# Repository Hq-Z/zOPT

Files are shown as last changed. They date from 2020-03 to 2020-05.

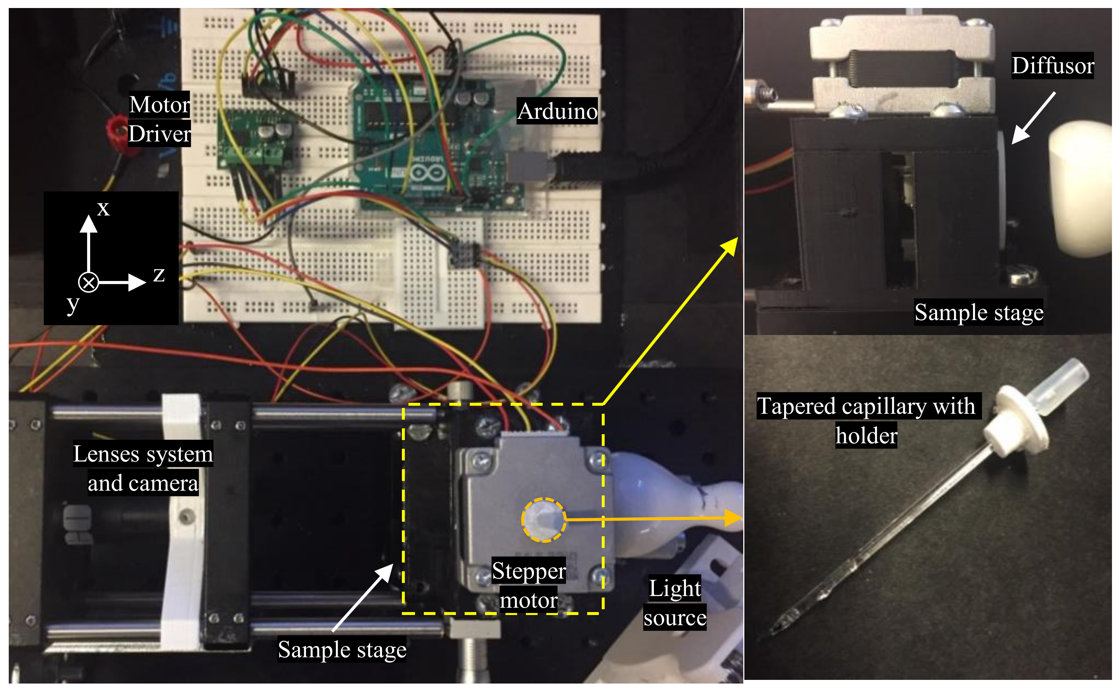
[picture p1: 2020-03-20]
1. 3D Models/SetupDemo/FigureS1.png

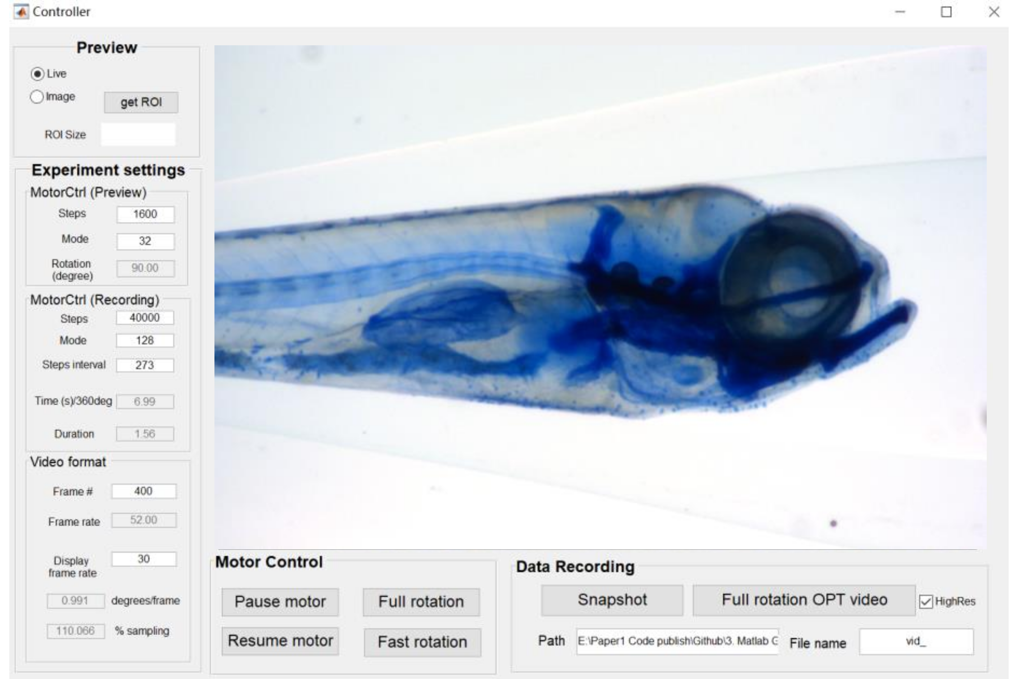
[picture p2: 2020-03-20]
3. Matlab GUI/GUI Demo/FigureS2.png

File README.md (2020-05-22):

# zOPT
This project contains an open-source implementation of an OPT platform. The 3D-printable components are provided to built your customized sample stage. We offer our open source MATLAB software with an GUI for OPT imaging. We developed a generalized automated workflow including a two-step registration approach for correcting the center of rotation and provide accurate and high-quality 3D reconstruction.

Here we provide the source codes and a user guide to built up the zOPT system. For sample data from the system, please follow this link,
https://sourceforge.net/projects/zopt-tomography-reconstruction.
We saved a bright field OPT tomography data recorded by our zOPT setup and it can be used to verify the algorithms for zOPT tomography reconstruction.

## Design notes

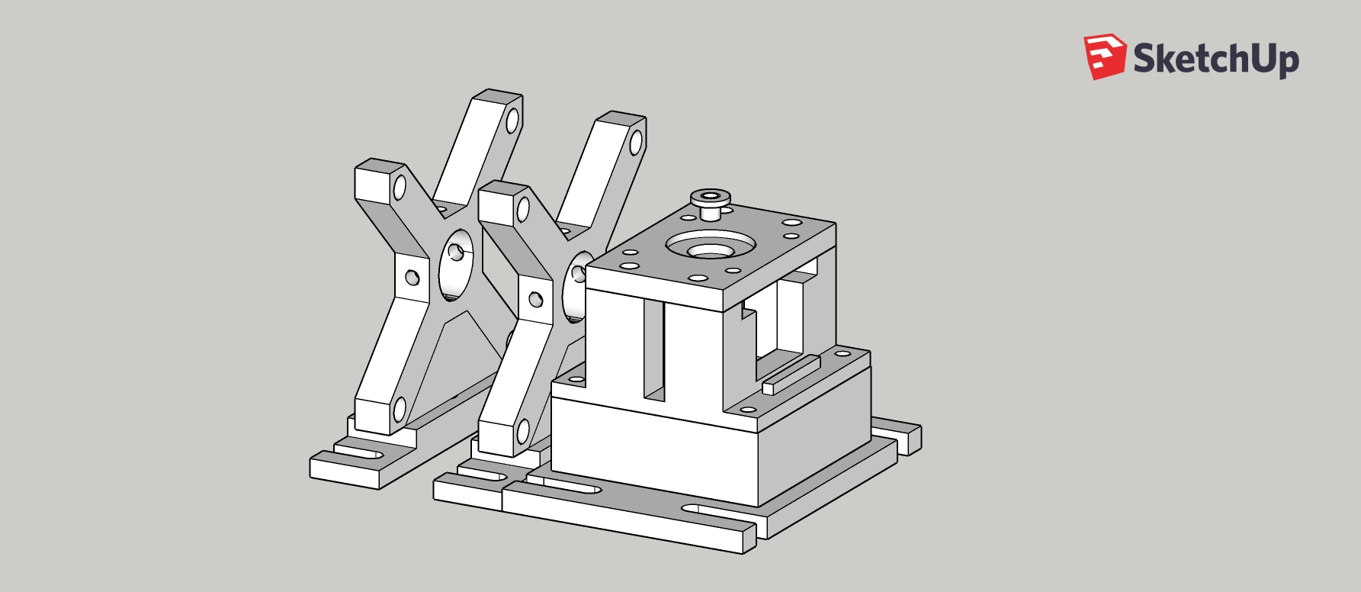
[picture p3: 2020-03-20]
1. 3D Models/stls/ALL.jpg

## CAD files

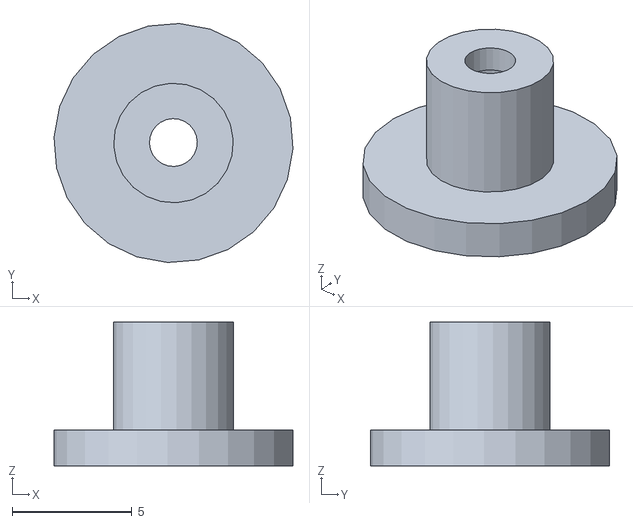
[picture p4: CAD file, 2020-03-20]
1. 3D Models/stls/CapillaryTube.stl
9.99 x 9.99 x 6.00

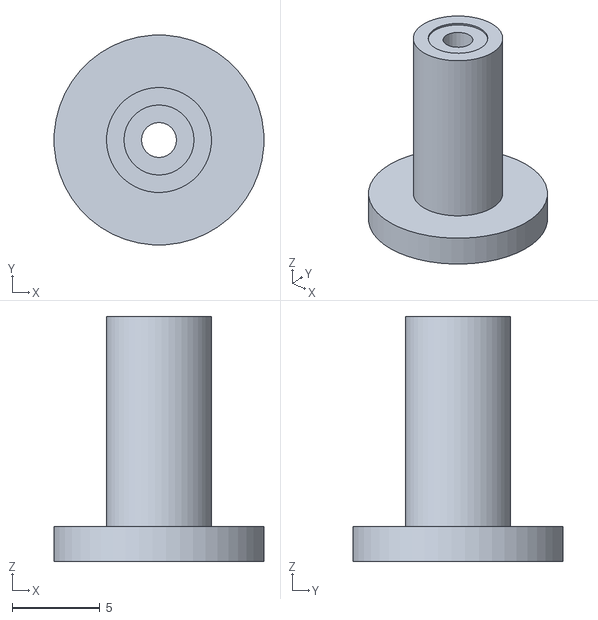
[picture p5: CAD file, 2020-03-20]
1. 3D Models/stls/ChamberTopPartB.stl
12.0 x 12.0 x 14.0

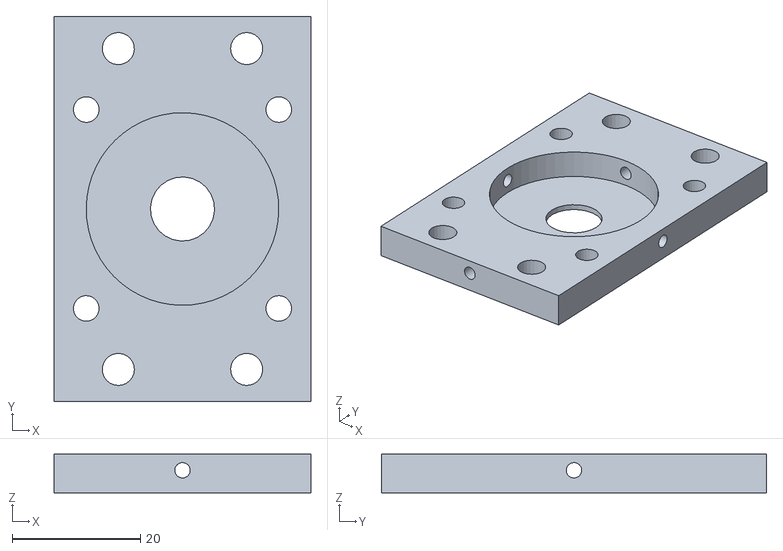
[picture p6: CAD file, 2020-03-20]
1. 3D Models/stls/ChamberTopPartA.stl
40.0 x 60.0 x 6.00

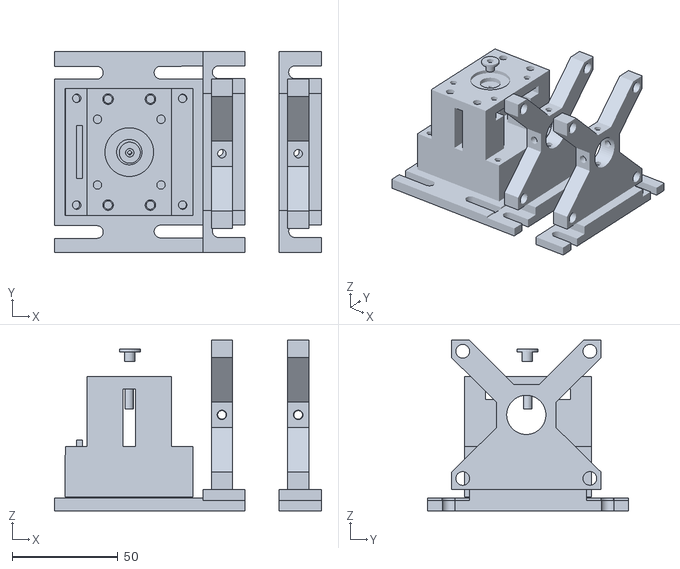
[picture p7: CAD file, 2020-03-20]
1. 3D Models/stls/ALL.stl
126.0 x 95.0 x 80.6

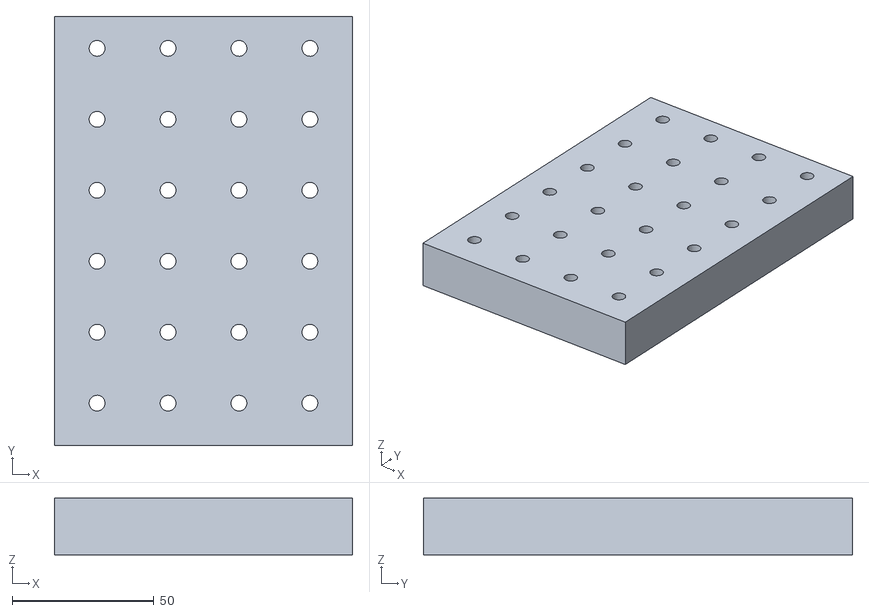
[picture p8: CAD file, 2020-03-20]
1. 3D Models/stls/Plate-Customized.stl
105.0 x 151.3 x 20.0

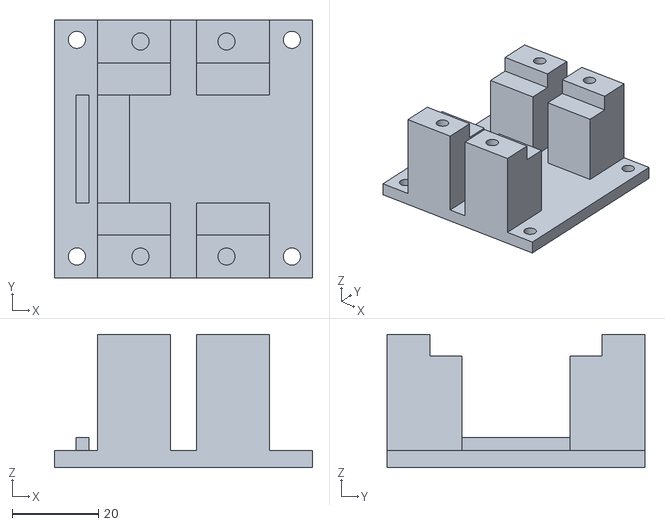
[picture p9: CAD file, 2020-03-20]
1. 3D Models/stls/ChamberMiddlePartA.stl
60.0 x 60.0 x 31.0

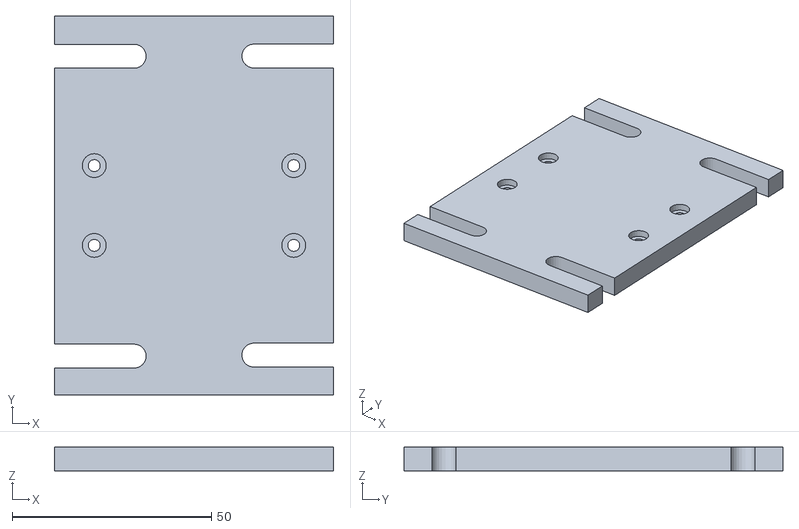
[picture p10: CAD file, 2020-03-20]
1. 3D Models/stls/ChamberBottom.stl
70.0 x 95.0 x 6.00

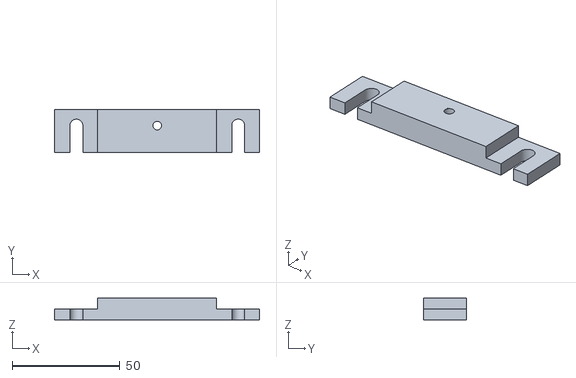
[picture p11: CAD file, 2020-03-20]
1. 3D Models/stls/LensSystemBottom.stl
95.0 x 20.0 x 10.0

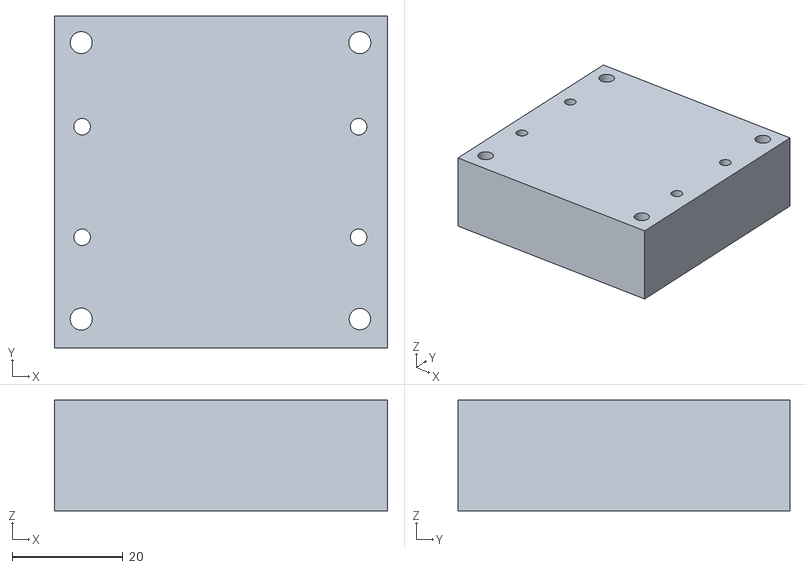
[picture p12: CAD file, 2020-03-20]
1. 3D Models/stls/ChamberMiddlePartB.stl
60.2 x 60.0 x 20.0

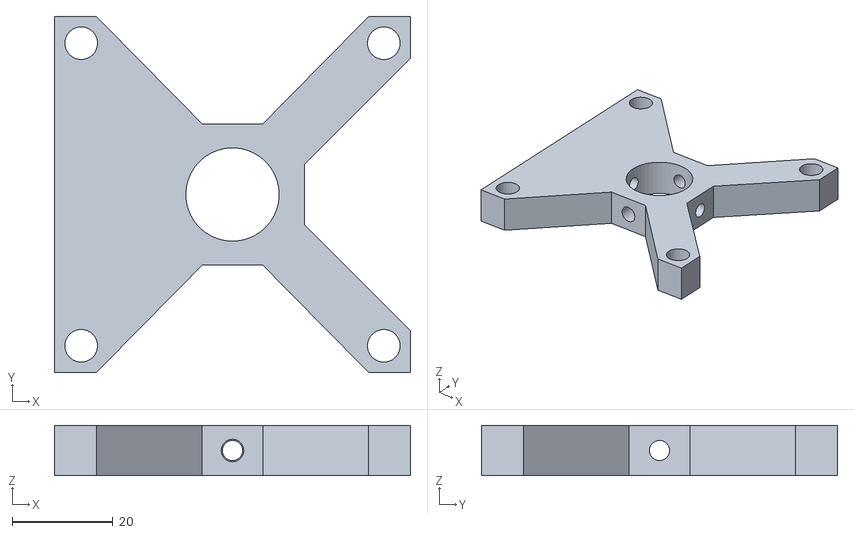
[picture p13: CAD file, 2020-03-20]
1. 3D Models/stls/LenSystemHolder.stl
70.6 x 70.6 x 10.0

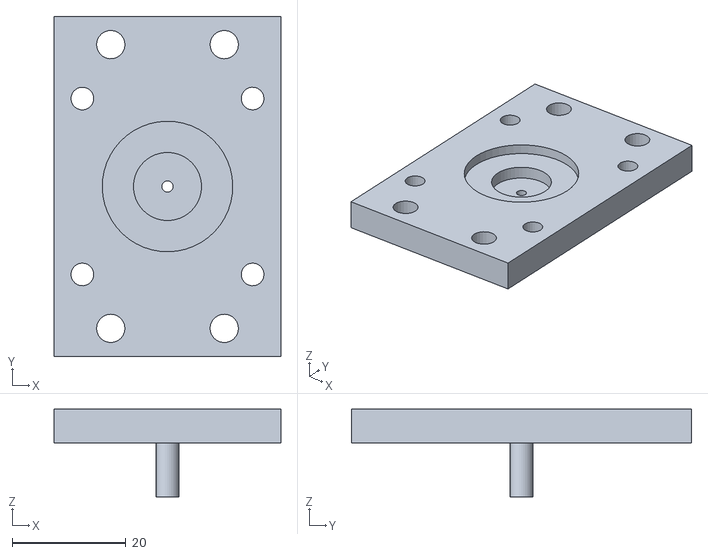
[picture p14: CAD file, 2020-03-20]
1. 3D Models/stls/ChamberTopPartAB.stl
40.0 x 60.0 x 15.5

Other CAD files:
1. 3D Models/Source/ALL.skp
1. 3D Models/Source/CapillaryTube.skp
1. 3D Models/Source/ChamberBottom.skp
1. 3D Models/Source/ChamberMiddlePartA.skp
1. 3D Models/Source/ChamberMiddlePartB.skp
1. 3D Models/Source/ChamberTopPartA.skp
1. 3D Models/Source/ChamberTopPartAB.skp
1. 3D Models/Source/ChamberTopPartB.skp
1. 3D Models/Source/LenSystemHolder.skp
1. 3D Models/Source/LensSystemBottom.skp

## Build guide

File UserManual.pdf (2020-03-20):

zOPT: an open source Optical Projection Tomography system and methods for rapid 3D zebrafish imaging HANQING ZHANG, LAURA WALDMANN, REMY MANUEL, TATJANA HAITINA, AMIN ALLALOU, Uppsala University, Sweden.

# zOPT user manual

This manual contains two sections to help you quickly get started with building up the setup and conducting experiment using our zOPT.

## 1. Experimental setup and GUI

To build an zOPT system, you need to purchase the components listed in Table.1. The list contains light source, lenses and cameras that we recommend. A 3D printer will be needed due to parts of the component are 3D printed. The .stl files for our 3D printable components can be found in https://github.com/Hq-Z/zOPT. We used the original version of Ultimaker and PLA (black, white) to print our components. After all the components are ready, we can build system as presented in Figure.1. In this figure, the optical components and sample stage is built on top of an aluminum breadboard with holes for fixing positions, while the white breadboard is used to connect wires for Arduino and drivers to control the stepper motor. The arrangement of the 3D components is presented in Figure. 2. The component 1 in Figure.2 is glued to a glass tapered capillary as shown in Figure.1. Other components can be fixed together either by glues or by nails. For connection amongst the Arduino, the driver, the stepper motor and the computer, please refer to the user manual from the manufacturer. After all electrical components are connected correctly, we can upload the codes to the Arduino for controlling the motor and a MATLAB GUI to complete the OPT recording.

| Item | Details | Cost €
1 | Broadband LED | LED clamp spotlight, warm white LED, IKEA | 13

2

Ground glass

diffuser

| | AR-Coated, N-BK7 Ground Glass Diffusers, Thorlabs | 12
3 | Quartz cuvette | #CG-F-20, The Science Outlet, Keota, OK | 15

4

Translation stage

(optional)

Unknown manufacturer, Equivalent to RB13M, 3 Axis

RollerBlock™ Long-Travel Stages,Thorlabs

(1388.91)

5 | Stepper motor | Jugetek, 39BYG55022-13K | 12
6 Motor drive carrier | AMIS-30543, Pololu | 14.3

7

Glass capillary

(optional)

40564010, Hecht Assistant; inner diameter 1.15 mm,

outer disameter 1.55

Glass capillary

(optional)

9530-2, PYREX, inner diamter 0.8-1.1 mm (2000 Pieces ) | (180)
Glass capillary | B150-86-15, SUTTER INSTRUMENT,inner diameter
(optional) | 0.86 mm, outer diameter 1.5 mm (250 Pieces)

(65.5)

8

Stage framework

and sample holder

| | 3D printable components | 5
9 | Arduino board | ARDUINO UNO REV3 | 28.4

10

Aluminum

breadboard

(optional)

Unknown manufacturer, Equivalent to MB2025/M,

Thorlabs

(111.15)

11

Telecentric lens

system

3X, 110 mm CompactTL, Edmund Optics, depth of field

0.36 mm

625

12

CCD camera

FLIR Blackfly S BFSU3-23S3C, pixel size of 3.45 × 3.45

µm

565

Table. S1 Component list of our customized OPT.

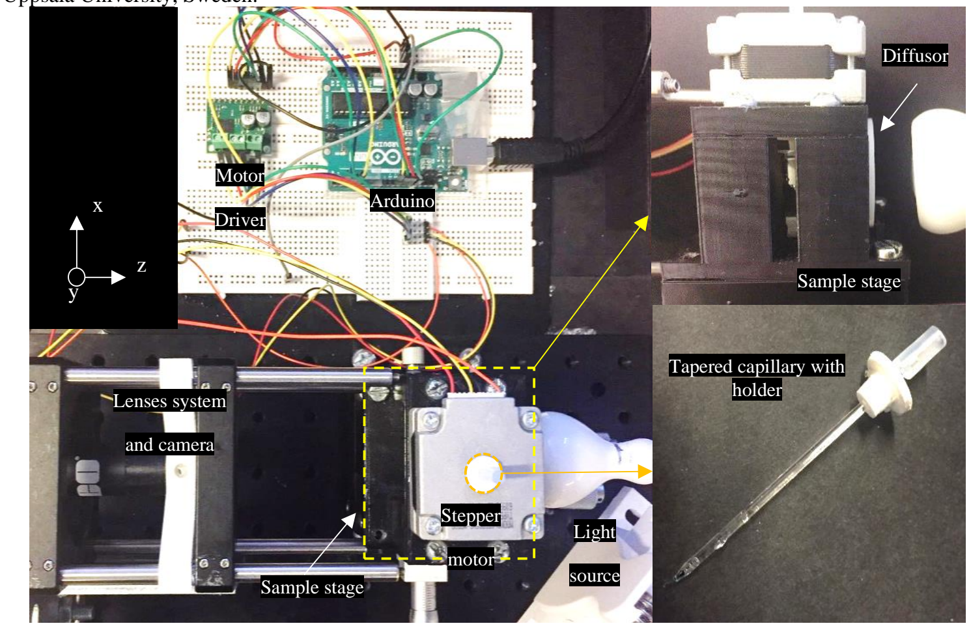
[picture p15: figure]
Lenses system; and camera; Sample stage; Motor; Driver; Arduino; Tapered capillary with holder; Light; motor; source; Diffusor; Stepper

Figure.1 Experimental setup of the brightfield OPT system. The dashed square indicates the area of sample stage from the top view and the side view of the stage can be found on the top right. The dashed circle shows the position of the capillary that goes through the stepper motor and the entire structure of the tapered capillary, holder for stepper motor and inlet-outlet port is shown on the bottom right.

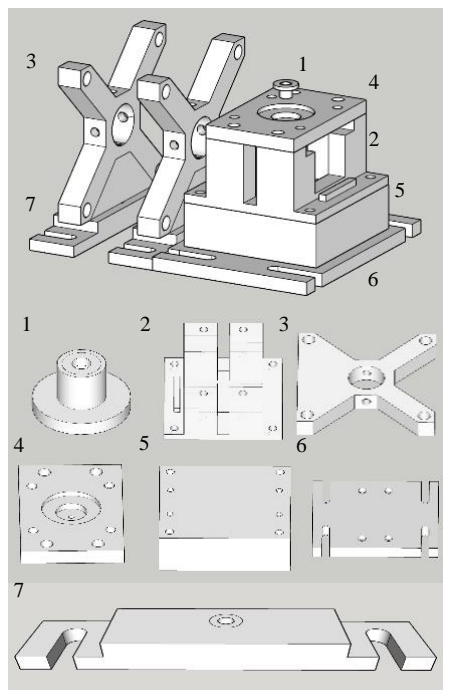
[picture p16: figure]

Figure. 2. Schematics of 3D printable components for the OPT system. The image above shows when printable components are placed together. Note that the position of each component can be fixed by the user using screws, glue or tape.

## 2. MATLAB GUI

To operate on the system, one need to install the Arduino IDE and MATLAB on your computer. We provide a MATLAB based GUI as shown in Figure. 3. The GUI allows us to control the stepper motor and to rotate the sample in real-time and record OPT data.

In our implementation, all connections to the computer is based on the USB port and we used drivers that are designed for the FLIR camera (USB 3.0) and used serial communication with the Arduino. We set the frame rate to 53 frames per second by default using the driver for FLIR Blackfly Camera in MATLAB. The specific camera settings, such as exposure time and color balance, can be changed manually using the FLIR SpinView software. Other cameras can also be used with the GUI. It searches for existing camera options if the FLIR camera cannot be

found.

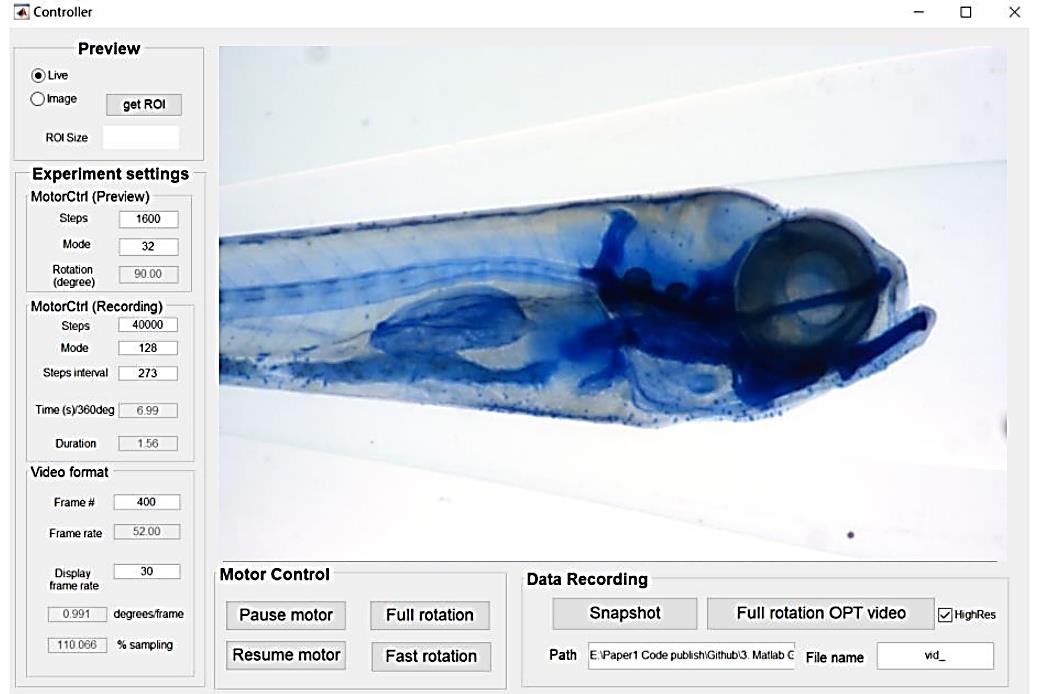
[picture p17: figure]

Figure. 3 GUI for OPT system based on MATLAB.

To record OPT data using the GUI, we recommend the following steps:

1. Start the software by running GUIOPT.m in MATLAB. Make sure the computer-camera connection as well as the computer-Arduino connection are connected. If the camera connection and detected properly image captured by the camera will appear in the GUI after selecting Live mode under the Preview panel. If the motor is connected, rotating the scroll wheel of the mouse and pointing on the image in the GUI will rotate the capillary accordingly.
2. Check the motor rotation and your sample. In Motor Control panel, clicking "Full rotation" provides a possibility to check the sample rotation for one revolution. The button "Fast rotation" spins the capillary at high speed. One can also control the capillary rotation by using the mouse scroll wheel as described above. In this case, the number of motor steps and mode for microstepping can be set in MotorCtrl (Preview) under Experiment Settings. By default the capillary rotates 90 degrees if the mouse wheel is moved one step. Note that the settings here are not controlling the sample rotation during data recording.
3. Set parameters for OPT data. The MotorCtrl (Recording) under Experiment Settings determines how the sample will rotate in OPT data. One can put in the number of steps, mode for microstepping and time interval in-between steps to achieve desired rotation time and duration. The duration is a relative measure and it is set to 1 for rotation of 360 degrees. The Video format under Experiment Settings sets the camera related parameters for OPT data, including the number of frames and video frame rate. In our setup, the frame rate for capturing new frames from the camera is fixed to 52 frames per second. The GUI automatically calculates the degree accuracy as well as the degrees in percentage (360 degrees as 100%) based on the motor and camera parameters.
4. Record and save file. Click the "Full rotation OPT video" under Data recording panel allows the system to obtain OPT data and save it to a local path by default and the file name can be specified by the user. Note that the preview will be closed during the recording of OPT data and recover after the saving is finished. By ticking the HighRes option, OPT video data will be saved uncompressed. Moreover, the button "Snapshot" saves single preview image. If a user wants to save OPT data within a ROI, click the button "get ROI" under the Preview panel. Drag the region in the image in the pop-up window and double-click to confirm the selection. The preview window will display the selected ROI length in horizontal and vertical direction in pixels. The default values for GUI can be changed in file initConfigurations.m.

Additionally, "Pause Motor" and "Resume Motor" enables and disables the motor. This function is optional depending if the stepper motor gets heated over time. The parameters for controlling the stepper motor are related to the settings in the codes for controlling Arduino. Make sure the Arduino codes are successfully uploaded to the Arduino board before running the MATLAB.

## Automated reconstruction

We offer three demo programs in MATLAB for OPT reconstruction. The file Demo1_2D_SyntheticData.m runs automatically by creating synthetic 2D objects, transformed them to tomography data for the algorithm to apply reconstruction algorithms. The same reconstruction algorithm is used in the file Demo2_2D_RealOPTData.m. However, in this case, the input data is selected by the user. We recommend testing the algorithm with our zebrafish video data from OPT where the horizontal axis is the rotation axis. A column number is pre-determined in this case and the data sampled from the selected column is used for reconstruction. The full 3D reconstruction of OPT data is conducted using the Demo3_3D_RealOPTData.m file. The user can load a test video, then specify the region-of-interest and the algorithm will apply automatic background detection, finding 360 degrees rotation and apply our gCOR and iRRpw algorithms for center-of-rotation correction and FBP is applied for reconstruction. Note that our algorithm does not require any pre-knowledge of the sample and the environment, such as an image with only the background or feature points for generating reconstruction results. The user can set some parameters in InitOPT.m, for example, set the region-of-interest in the video or set the maximum iteration in the iRRpw algorithm to balance between performance and accuracy.

## System Requirement for OPT Reconstruction using MATLAB

For running the GUI and script for center-of-rotation (COR) correction and reconstructing 3D OPT data, we tested our GUI using MATLAB 2018b and operate on Windows 10 system a 3.2 GHz Intel Core i7-8700 processor with 32 GB RAM, 256 GB SSD hard disk. The reconstruction of 855×855×950 voxels data, single-channel and with 3 iterations with our iRRpw algorithm is tested using MATLAB 2018b. It takes approximately 6 min to complete the iterations and we are using NVIDIA GeForce GTX 1060 for GPU acceleration.

Moreover, the GUI for save videos requires the time for extracting frames from the camera buffer to the hard disk to be reasonably short (at a maximum of 60s). The saving can fail if the user is trying to save the data to a slow hard disk or using a portable hard drive with slow USB connection. The reconstruction is dependent on the video frame size, so make sure to select proper size of ROI to match your computing resources.

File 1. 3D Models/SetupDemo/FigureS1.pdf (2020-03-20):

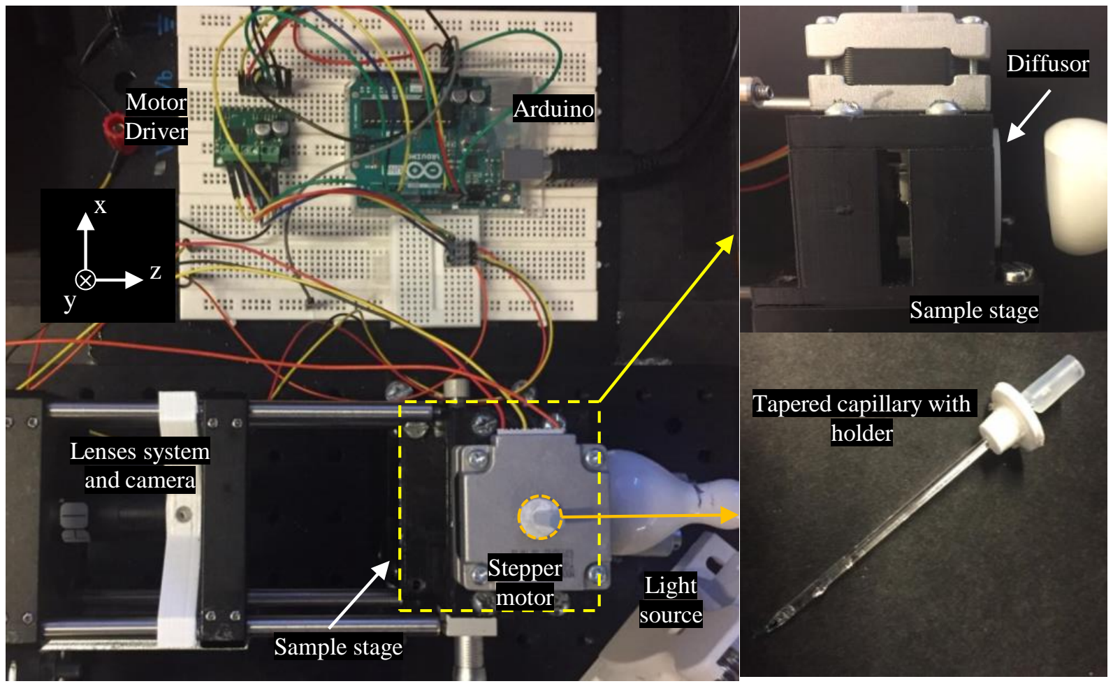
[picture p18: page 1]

Lenses system
and camera

Sample stage

Motor
Driver

Arduino

Tapered capillary with
holder

Light
source

Sample stage

Diffusor

×

z
y

x

Stepper
motor

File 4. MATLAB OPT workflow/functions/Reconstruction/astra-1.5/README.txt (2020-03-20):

-----------------------------------------------------------------------
This file is part of the ASTRA Toolbox

Copyright: 2010-2015, iMinds-Vision Lab, University of Antwerp
           2014-2015, CWI, Amsterdam
           http://visielab.uantwerpen.be/ and http://www.cwi.nl/
License: Open Source under GPLv3
Contact: astra@uantwerpen.be
Website: http://sf.net/projects/astra-toolbox
-----------------------------------------------------------------------

The ASTRA Toolbox is a MATLAB toolbox of high-performance GPU primitives
for 2D and 3D tomography.

We support 2D parallel and fan beam geometries, and 3D parallel and cone beam.
All of them have highly flexible source/detector positioning.

A large number of 2D and 3D algorithms are available, including FBP, SIRT,
SART, CGLS.

The basic forward and backward projection operations are GPU-accelerated,
and directly callable from MATLAB to enable building new algorithms.

This Windows release comes with a pre-built Python interface as well. See
the file README.txt the python/ subdirectory for details.

Documentation / samples:
-------------------------

See the matlab code samples in samples/ and on
http://sf.net/projects/astra-toolbox .

Installation instructions:
---------------------------

Windows, binary:
-----------------

Add the mex and tools subdirectories to your matlab path.

Linux, from source:
--------------------

Requirements: g++, boost, CUDA (driver+toolkit), matlab

cd build/linux
./configure --with-cuda=/usr/local/cuda \
            --with-matlab=/usr/local/MATLAB/R2012a \
            --prefix=/usr/local/astra
make
make install
Add /usr/local/astra/lib to your LD_LIBRARY_PATH.
Add /usr/local/astra/matlab and its subdirectories (tools, mex)
  to your matlab path.

NB: Each matlab version only supports a specific range of g++ versions.
Despite this, if you have a newer g++ and if you get errors related to missing
GLIBCXX_3.4.xx symbols, it is often possible to work around this requirement
by deleting the version of libstdc++ supplied by matlab in
MATLAB_PATH/bin/glnx86 or MATLAB_PATH/bin/glnxa64 (at your own risk).

Windows, from source using Visual Studio 2008:
-----------------------------------------------

Requirements: Visual Studio 2008, boost, CUDA (driver+toolkit), matlab.
Note that a .zip with all required (and precompiled) boost files is
  available from our website.

Set the environment variable MATLAB_ROOT to your matlab install location.
Open astra_vc08.sln in Visual Studio.
Select the appropriate solution configuration.
  (typically Release_CUDA|win32 or Release_CUDA|x64)
Build the solution.
Install by copying AstraCuda32.dll or AstraCuda64.dll from bin/ and
  all .mexw32 or .mexw64 files from bin/Release_CUDA or bin/Debug_CUDA
  and the entire matlab/tools directory to a directory to be added to
  your matlab path.

References:
------------

If you use parallel beam GPU code for your research, we would appreciate it if
you would refer to the following paper:

W. J. Palenstijn, K J. Batenburg, and J. Sijbers, "Performance improvements
for iterative electron tomography reconstruction using graphics processing
units (GPUs)", Journal of Structural Biology, vol. 176, issue 2, pp. 250-253,
2011

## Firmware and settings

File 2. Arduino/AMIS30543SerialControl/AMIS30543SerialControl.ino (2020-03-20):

#include <SPI.h>
#include <AMIS30543.h>
#include <AccelStepper.h>
// -------------------------------------------------------------------------
//  Please refer to our paper for more details:
// 
//  "zOPT: an open source Optical Projection Tomography system and methods for
//  rapid 3D zebrafish imaging"
//  HANQING ZHANG,LAURA WALDMANN,REMY MANUEL,TATJANA HAITINA,AND AMIN ALLALOU
//  
//  Authors information:
//    hanqing.zhang@it.uu.se
//    amin.allalou@it.uu.se
// 
//  Copyright 2020,  1. BioImage Informatics Facility at SciLifeLab,Sweden
//                   2. Division of Visual information and interaction, 
//                      Department of Information Technology, Uppsala university,Sweden
// 
//  License: The program is distributed under the terms of the GNU General 
//  Public License v3.0
//  Contact: Version 1.0 - first release, 20200207, zhanghq0088@gmail.com
//  Website: https://github.com/Hq-Z/zOPT
// -------------------------------------------------------------------------

// Assign default pins AMIS30543
const uint8_t amisDirPin = 2;
const uint8_t amisStepPin = 3;
const uint8_t amisSlaveSelect = 4;

const int InitialTimeStep =700;
const int AcceleratingTimeStep= 1;
const int FinalTimeStep= 250; // !This is for fast rotation. Change this depending on the quality of your motor. smaller number faster rotation.

// Assign registers names for AMIS30543
enum regAddr
{
  WR  = 0x0,
  CR0 = 0x1,
  CR1 = 0x2,
  CR2 = 0x3,
  CR3 = 0x9,
  SR0 = 0x4,
  SR1 = 0x5,
  SR2 = 0x6,
  SR3 = 0x7,
  SR4 = 0xA,
};

// Set initial user parameters
int pulseWidth=2; // Pulse width for stepping, microseconds

int numSteps = 1000; // Number of micro-steps per 'step'
long numStepsFloat = 1000; // Number of micro-steps per 'step'
int speedDelay = 200; // Time delay of each step signal in microseconds

int currentLimit=128; // Maximum driving current for motor in miliamp.
int microsteps=32; // number of micro-steps in a full step.

int serialCommDelay=25; // Time delay

int substeps= 32; 
int substeps_tmp= 0; 

// Set Driver AMIS30543
AMIS30543 stepper;

void setup()
{
  // Turn off the yellow LED.
  pinMode(LED_BUILTIN, OUTPUT);

  // Serial and SPI communication
  digitalWrite(SS, HIGH);  // ensure SS stays high
  SPI.begin();
  stepper.init(amisSlaveSelect);
  SPI.attachInterrupt();

    // Ready
  digitalWrite(LED_BUILTIN, HIGH); // Turn on the yellow LED.
  delay(1000);
  digitalWrite(LED_BUILTIN, LOW); // Turn on the yellow LED.
  delay(1000);

  Serial.begin(9600);

  // Drive the NXT/STEP and DIR pins low initially.
  digitalWrite(amisStepPin, LOW);
  pinMode(amisStepPin, OUTPUT);
  digitalWrite(amisDirPin, LOW);
  pinMode(amisDirPin, OUTPUT);

  // Give the driver some time to power up.
  delay(1);

  // Reset the driver to its default settings.
  stepper.resetSettings();
  delay(1);
  
  // Set the current limit. 
  stepper.setCurrentMilliamps(currentLimit);
  // Set the number of microsteps that correspond to one full step.
  stepper.setStepMode(microsteps);

  // Enable the motor outputs.
  stepper.enableDriver();
  setDirection(0);
  
  // Serial monitor menu
  Serial.println(F(" m = mode")); 
  Serial.println(F(" r = dir anti clockwise "));
  Serial.println(F(" l = dir clockwise"));
  Serial.println(F(" e = driver on "));
  Serial.println(F(" o = driver in stand by"));
  Serial.println(F(" s = step"));
  Serial.println(F(" v = vstep"));
  Serial.println(F(" f = frequency or speed"));
  Serial.println(F(" p = sleep mode"));
  Serial.println(F(" w = stop sleep mode"));
  Serial.println(F(" i = show current status"));

  // Ready
  digitalWrite(LED_BUILTIN, HIGH); // Turn on the yellow LED.
  delay(1000);
}

void loop()
{
  //check serial port for 
  if (Serial.available()) {
    int charnr=0;
    char command;
    String readString;
    // Check command type
    while (Serial.available()) {
      delay(5);  // Time for acquiring data
      if (Serial.available() >0) { 
        char c = Serial.read();
        if (charnr==0)
          command=c;
        else
          readString += c;
        charnr++;
        }
      }
    Serial.println(readString);
    // Operations based on each command
    switch (command) { 
    case 'e': 
         stepper.enableDriver();
         if (stepper.driver.readReg(CR2) != 0x80)
          {
            Serial.println(F("Error: EnableDriver failed."));
            error();
          }
          else
          {
            Serial.println("Driver on ");
            delay(serialCommDelay);
          }
          break;
    case 'o':
          stepper.disableDriver(); 
          if (stepper.driver.readReg(CR2) != 0x00)
          {
            Serial.println(F("Error: DisableDriver failed."));
            error();
          }
          else
          {
            Serial.println("Driver off");
            delay(serialCommDelay);
          }
          break;
    case 'p': 
          stepper.enableDriver();
          stepper.sleep();
          Serial.println("Driver is on sleep mode");
          delay(serialCommDelay);
          break;
    case 'w': 
          stepper.enableDriver();
          stepper.sleepStop();
          Serial.println("Driver has stopped sleep mode");
          delay(serialCommDelay);
          break;
  // motor direction
    case 'l': 
          stepper.setDirection(0);
          Serial.println("Direction clock wise");
          delay(serialCommDelay);
          break;
  // define the ccw motor direction 
    case 'r': 
          stepper.setDirection(1);
          Serial.println("Direction counter clock wise");
          delay(serialCommDelay);
          break;
    case 's':
           //numSteps=readString.toInt();
           numStepsFloat=atol(readString.c_str());
           Serial.println(F("Step number is set to "));
           Serial.println(numSteps, DEC);
           Serial.println(F(" steps."));
           stepFloat(numStepsFloat,speedDelay);
           //step(numSteps,speedDelay);
           Serial.println(F("Completed"));
           break;
    case 'v': 
           numSteps=readString.toInt();
           Serial.println(F("Fast mode on : "));
           Serial.println(numSteps, DEC);
           Serial.println(F(" steps."));
           Faststep(numSteps);
           Serial.println(F("Fast mode off"));
           break;
    case 'f': // speed number
            speedDelay=readString.toInt();
            Serial.println(F("Delay time between steps is "));
            Serial.println(speedDelay, DEC);
            Serial.println(F("microscronds."));
            //step(numSteps,speedDelay);
            break;
    case 't': // speed number
       
            if (readString[0] == 'l')
            {
              stepper.setDirection(0); 
              Serial.println(F("Dir 0 "));
            }
            else
            {
              stepper.setDirection(1);
              Serial.println(F("Dir 1 "));
            }
              
           numSteps=readString.substring(1).toInt();
           //Serial.println(F("Step number is set to "));
           //Serial.println(numSteps, DEC);
           //Serial.println(F(" steps."));
           step(numSteps,speedDelay);
           //Serial.println(F("Completed"));
           break;
    case 'm': 
           substeps_tmp=readString.toInt();
           if(substeps_tmp>0)
           {  if(substeps_tmp<2)
              {
                substeps=1;
              }
              else if(substeps_tmp<4)
              {
                substeps=2;
              }
              else if(substeps_tmp<8)
              {
                substeps=4;
              }
              else if(substeps_tmp<16)
              {
                substeps=8;
              }
              else if(substeps_tmp<32)
              {
                substeps=16;
              }
              else if(substeps_tmp<64)
              {
                substeps=32;
              }
              else if(substeps_tmp<128)
              {
                substeps=64;
              }
              else if(substeps_tmp<256)
              {
                substeps=128;
              }
              else
              {
                substeps=32;
              }
            }
            else
            { 
              substeps=32;
            }
           Serial.println(F("The number of sub steps are "));
           Serial.println(substeps, DEC);
           stepper.setStepMode(substeps);
           //step(numSteps,speedDelay);
           break;
     case 'i': 
         uint8_t cr2 = readReg(CR2);
         if (cr2 == 0xC0)
         {
          Serial.println(F("SleepMode: On "));
          Serial.println(F("Driver: Enabled "));
         }
         else if (cr2 == 0x80)
         {
           Serial.println(F("SleepMode: Off "));
           Serial.println(F("Driver: Enabled "));
         }
         else if (cr2 == 0x00)
         {
          Serial.println(F("SleepMode: unknown "));
          Serial.println(F("Driver: Disabled "));
         }
         else
         {
           Serial.println(F("SleepMode: unknown "));
           Serial.println(F("Driver: unknown "));
          }

         Serial.println(F("Current limit is set to "));
         Serial.println(currentLimit, DEC);
         
         Serial.println(F("Step number is set to "));
         Serial.println(numSteps, DEC);
           
         Serial.println(F("Delay time between steps is "));
         Serial.println(speedDelay, DEC);

         Serial.println(F("The number of sub steps are "));
         Serial.println(substeps, DEC);
    }
    }
}

// Sends a pulse on the NXT/STEP pin to tell the driver to take
// one step, and also delays to control the speed of the motor.
void step(int numSteps,int speedDelay)
{
  // The NXT/STEP minimum high pulse width is X microseconds.
  for ( int i = 0; i < numSteps; i++) {
    digitalWrite(amisStepPin, HIGH);
    delayMicroseconds(pulseWidth);
    digitalWrite(amisStepPin, LOW);
    delayMicroseconds(pulseWidth);
    // The delay here controls the stepper motor's speed.  You can
    // increase the delay to make the stepper motor go slower.  If
    // you decrease the delay, the stepper motor will go fast, but
    // there is a limit to how fast it can go before it starts
    // missing steps.
    delayMicroseconds(speedDelay);
  }
}
void stepFloat(long numSteps,int speedDelay)
{
  // The NXT/STEP minimum high pulse width is X microseconds.
  for ( long i = 0; i < numSteps; i++) {
    digitalWrite(amisStepPin, HIGH);
    delayMicroseconds(pulseWidth);
    digitalWrite(amisStepPin, LOW);
    delayMicroseconds(pulseWidth);
    // The delay here controls the stepper motor's speed.  You can
    // increase the delay to make the stepper motor go slower.  If
    // you decrease the delay, the stepper motor will go fast, but
    // there is a limit to how fast it can go before it starts
    // missing steps.
    delayMicroseconds(speedDelay);
  }
}

void Faststep(int numSteps){  // Acceleration part
 digitalWrite(amisStepPin, HIGH);
 for (int i = InitialTimeStep; i > FinalTimeStep; i = i-AcceleratingTimeStep){
   for (int x = 0; x < 200; x++) {
    digitalWrite(amisStepPin, HIGH);
    delayMicroseconds(i);
    digitalWrite(amisStepPin, LOW);
    delayMicroseconds(i);
   }
}

 for (int i = InitialTimeStep; i < numSteps; i = i++) {
     for (int x = 0; x < 200; x++) {
     digitalWrite(amisStepPin, HIGH);
     delayMicroseconds(FinalTimeStep);
     digitalWrite(amisStepPin, LOW);
     delayMicroseconds(FinalTimeStep);
    }
 }

}
// Writes a high or low value to the direction pin to specify
// what direction to turn the motor.
void setDirection(bool dir)
{
  // The NXT/STEP pin must not change for at least 0.5
  // microseconds before and after changing the DIR pin.
  delayMicroseconds(1);
  digitalWrite(amisDirPin, dir);
  delayMicroseconds(1);
}

uint8_t readReg(uint8_t address)
{
  return stepper.driver.readReg(address);
}

void error()
{
  stepper.disableDriver();
  while(1)
  {
  }
}
